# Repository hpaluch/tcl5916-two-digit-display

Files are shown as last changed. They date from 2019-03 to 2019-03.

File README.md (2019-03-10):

# Connecting 7-segment 2-digit display to TLC5916

Here is project how to use 2x TLC5916 with 7-segment 2-digit
LED display.

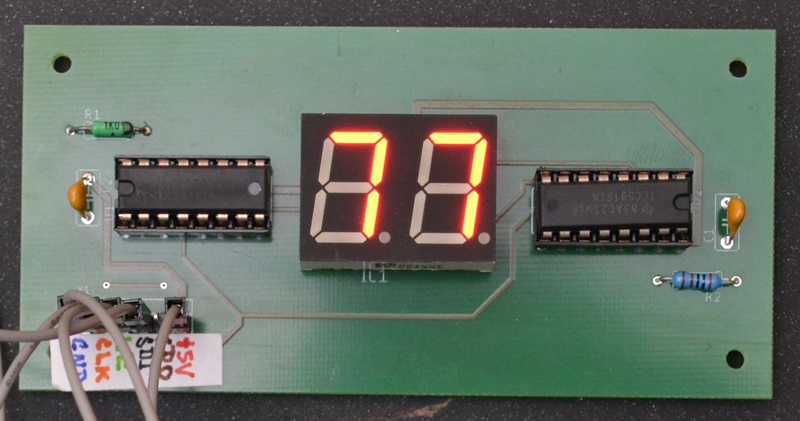
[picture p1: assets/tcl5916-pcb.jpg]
PCB with TLC5916 in action
 

Board revision 1.0 (initial) is shown on picture.

Project status:

Board was tested successfully. See 
subproject [Connecting TLC5916 to PC using LC 341A USB adapter][Connecting TLC5916 to PC using LC 341A USB adapter] for example.

# Design files

Design files are in revision 1.1, 2019-03-10. New values
of R1 and R2 were computed using this setup:

The relation between R<sub>ext</sub> and I<sub>led</sub> is following
(default configuration after power-up):

1. To get `I_led` in `[mA]` from `R_ext` in `[kOhm]` use:

   ```
   I_led = 1.25 * 15 / R_ext = 18.75 / R_ext
   ```
   
   For example (used in our circuit now): `R_ext = 1 [kOhm]` => `I_led = 18.75 [mA]` 
   
2. To get `R_ext` in `[kOhm]` from `I_led` in `[mA]` use:

   ```
   R_ext = 1.25 * 15 / I_led = 18.75 / I_led
   ```    

   For example: `I_led = 20 [mA]` => `R_ext = 0.937 [kOhm] = 937 [Ohm]`

Also see `Figure 4. Output Current vs Output Voltage` in data sheet
to verify that `VLED` (voltage connected to common LED anode) 
must be greater than `Voltage drop on LED` + `1V` (roughly).
In our case using `+5V` voltage is OK.

Design was done in [Eagle 9.3.0 Free][Eagle 9.3.0 Free]

Schematic is:

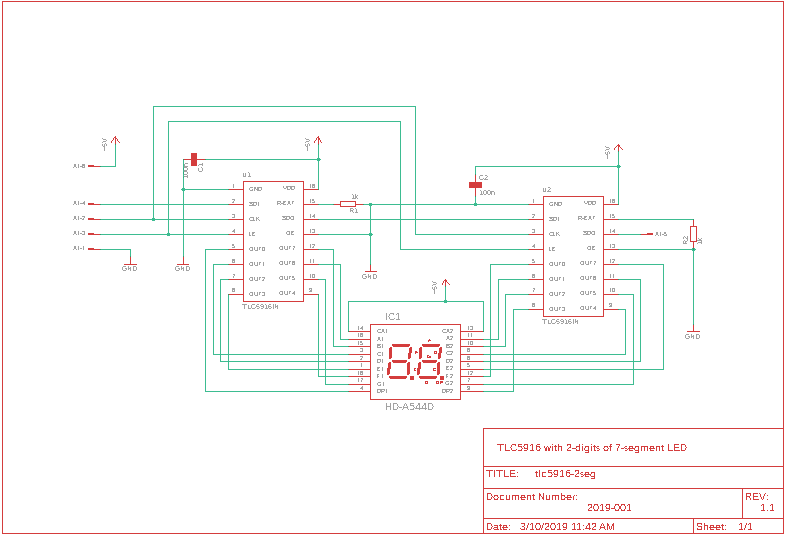
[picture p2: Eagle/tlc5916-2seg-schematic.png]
Schematic of TLC5916 with LED display
 

Also in:
* [PDF version][Schematic PDF]
* [Eagle 9.3.0 Free version][Schematic Eagle]

PCB design is:

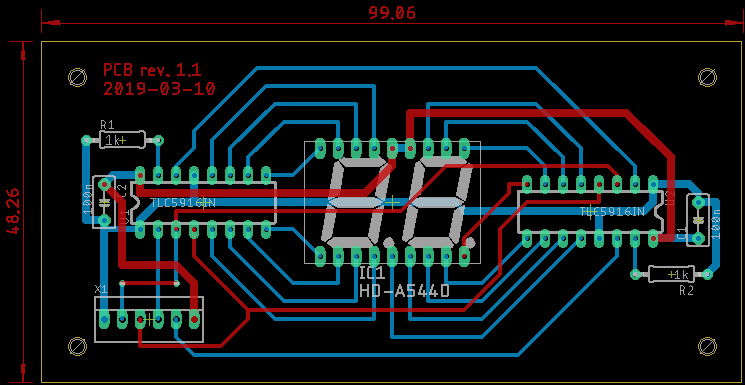
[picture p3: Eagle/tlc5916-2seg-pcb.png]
PCB of TLC5916 with LED display
 

Also in:
* [PDF version][PCB PDF]
* [Eagle 9.3.0 Free version][PCB Eagle]

Following Eagle libraries were used:

* [zlalanne/eagle-library][zlalanne/eagle-library] for
  definition of [TLC5916][TLC5916]
* [moje.lbr][moje.lbr] - my own part library (originally for Eagle 3/DOS)
  made in late 90's in college - 
  used definition of [2-digit HD-A544D LED display][HD-A544D]

Board was made by [gatema.cz][gatema.cz] for
around 700 CZK (roughly 32 USD) including:

* 2 layers
* plated holes
* solder mask
* top silk screen

NOTE: Remember to follow instructions in 
[eagle-dokumentace.pdf][eagle-dokumentace.pdf]
from [Technicke informace][Technicke informace]
(provided in Czech only)

# Bill of Material

* 2x [TLC5916][TLC5916 - tme.eu] - from tme.eu
* LED display [HD-A544D][HD-A544D] - from gme.cz
* 2x 1K resistor - from my inventory
* 2x 100nF capacitor - from my inventory
* pinhead connector 6 pins in 1 row - used
  20-pin [DS1021-1x20SF1-10][DS1021-1x20SF1-10] - from gme.cz

# Connecting TLC5916 to Interfaces

There are following subprojects:
* [Connecting TLC5916 to PC using LC 341A USB adapter][Connecting TLC5916 to PC using LC 341A USB adapter] - connecting
  this board to PC with USB adapter

# Known bugs/limitations

Design shortcomings:
* digital signals (`CLK`, `SDI`, `SDO`, `LE`) should be routed more
  carefully - not crossing `LED` lines (where are high current spikes).
* LED display power supply pins (`13` and `14`) should be
  wired  to `+5V` supply through jumper pins
  to allow custom power supply (for example `+12V`) different
  from main circuit `+5V` power supply.

[Technicke informace]: https://www.gatema.cz/plosne-spoje/technicke-informace/default/7?do=reloadInfo
[eagle-dokumentace.pdf]: http://www.gatema.cz/file-link/eagle-dokumentace.pdf
[gatema.cz]: https://extranet.gatema.cz/dps/konfiguratorpool.aspx
[DS1021-1x20SF1-10]: https://www.gme.cz/oboustranny-kolik-s1g20-2-54mm-v-13-80mm
[TLC5916 - tme.eu]: https://www.tme.eu/en/details/tlc5916in/led-drivers/texas-instruments/
[Connecting TLC5916 to PC using LC 341A USB adapter]: https://github.com/hpaluch/tlc5916-two-digit-display/tree/master/ch341-tlc5916
[HD-A544D]: https://www.gme.cz/led-display-14-2mm-red-hd-a544d
[moje.lbr]: https://github.com/hpaluch/tlc5916-two-digit-display/blob/master/Eagle/moje.lbr?raw=true
[TLC5916]: http://www.ti.com/lit/ds/slvs695d/slvs695d.pdf
[zlalanne/eagle-library]: https://github.com/zlalanne/eagle-library/blob/master/lbr/zlalanne.lbr
[PCB Eagle]: https://github.com/hpaluch/tlc5916-two-digit-display/blob/master/Eagle/tlc5916-2seg.brd?raw=true
[PCB PDF]: https://github.com/hpaluch/tlc5916-two-digit-display/blob/master/Eagle/tlc5916-2seg-pcb.pdf?raw=true
[Schematic Eagle]: https://github.com/hpaluch/tlc5916-two-digit-display/blob/master/Eagle/tlc5916-2seg.sch?raw=true
[Schematic PDF]: https://github.com/hpaluch/tlc5916-two-digit-display/blob/master/Eagle/tlc5916-2seg-sch.pdf?raw=true
[Eagle 9.3.0 Free]: https://www.autodesk.com/products/eagle/free-download

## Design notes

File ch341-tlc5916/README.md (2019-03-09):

# Connecting TLC5916 to PC using LC 341A USB adapter

> WARNING!
>
> Work in progress.

>  Currently sends `0` to `0xF` decoded to
>  to 1st and to 2nd digits (showing same value on both digits)

Please see [master project README][2-digit 7-segment LED with TLC5916]
for Schematic and/or PCB.

Here is VisualStudio 2010 project to control 
[2-digit 7-segment LED with TLC5916][2-digit 7-segment LED with TLC5916]
using 
[CH341A USB to UART/IIC/SPI/TTL/ISP adapter EPP/MEM Parallel converter][CH341A USB to UART/IIC/SPI/TTL/ISP adapter EPP/MEM Parallel converter]

Please see one of my CH341 projects, for example
[Accessing Microwire EEPROM 93LC86 from LC CH341A USB using SPI mode][Accessing Microwire EEPROM 93LC86 from LC CH341A USB using SPI mode]
for generic HW/SW setup instructions. Here is project specific info only.

# Wiring LC CH341A USB adapter with [TLC5916 LED board][2-digit 7-segment LED with TLC5916] and Logic Analyzer

Wire all 3 things together using table below:

|CH341A pin|Direction from CH341A|TLC5916 pin|Logic Analyzer pin|Description|
|---|---|---|---|---|
|GND|N/A|GND|GND|Common ground|
|CS0|Output|LE|CH1|Latch Enable - active in HIGH|
|CS1|Output|CLK|CH2|Clock - active in rising edge|
|CS2|Output|N/A|CH4|Fake /SS (slave select)<sup>1</sup>|
|MOSI|Output|SDI|CH3|serial data for TLC5916|

NOTE: The [TLC5916 LED board][2-digit 7-segment LED with TLC5916]
      uses its own `+5V` power supply,
      because the drawn current can be quite high - because
      of up to 16 LED lighting together...

<sup>1</sup>) trick so SPI decoder in Logic Analyzer will work with these data
  (that are not otherwise SPI compatible)

# Logic Analyzer output

Here is sample output sending 0xA5 data to TLC5916 (just for test):

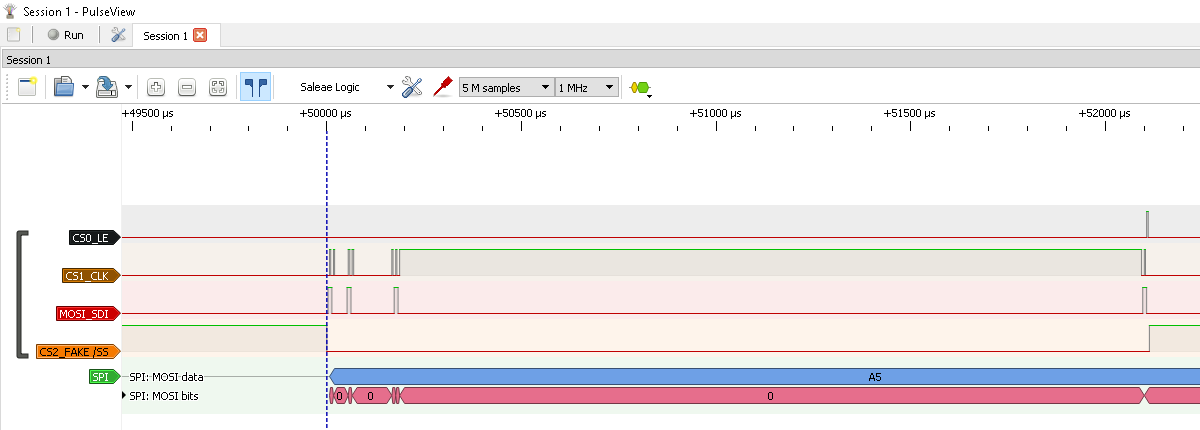
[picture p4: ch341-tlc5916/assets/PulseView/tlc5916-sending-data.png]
Sending data to TLC5916


[Accessing Microwire EEPROM 93LC86 from LC CH341A USB using SPI mode]: https://github.com/hpaluch/ch341-spi-93lc86 
[CH341A USB to UART/IIC/SPI/TTL/ISP adapter EPP/MEM Parallel converter]: http://www.chinalctech.com/cpzx/Programmer/Serial_Module/2019/0124/266.html 
[2-digit 7-segment LED with TLC5916]: https://github.com/hpaluch/tlc5916-two-digit-display

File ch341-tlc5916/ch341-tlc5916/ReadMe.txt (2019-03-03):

========================================================================
    CONSOLE APPLICATION : ch341-tlc5916 Project Overview
========================================================================

AppWizard has created this ch341-tlc5916 application for you.

This file contains a summary of what you will find in each of the files that
make up your ch341-tlc5916 application.

ch341-tlc5916.vcxproj
    This is the main project file for VC++ projects generated using an Application Wizard.
    It contains information about the version of Visual C++ that generated the file, and
    information about the platforms, configurations, and project features selected with the
    Application Wizard.

ch341-tlc5916.vcxproj.filters
    This is the filters file for VC++ projects generated using an Application Wizard. 
    It contains information about the association between the files in your project 
    and the filters. This association is used in the IDE to show grouping of files with
    similar extensions under a specific node (for e.g. ".cpp" files are associated with the
    "Source Files" filter).

ch341-tlc5916.cpp
    This is the main application source file.

/////////////////////////////////////////////////////////////////////////////
Other standard files:

StdAfx.h, StdAfx.cpp
    These files are used to build a precompiled header (PCH) file
    named ch341-tlc5916.pch and a precompiled types file named StdAfx.obj.

/////////////////////////////////////////////////////////////////////////////
Other notes:

AppWizard uses "TODO:" comments to indicate parts of the source code you
should add to or customize.

/////////////////////////////////////////////////////////////////////////////

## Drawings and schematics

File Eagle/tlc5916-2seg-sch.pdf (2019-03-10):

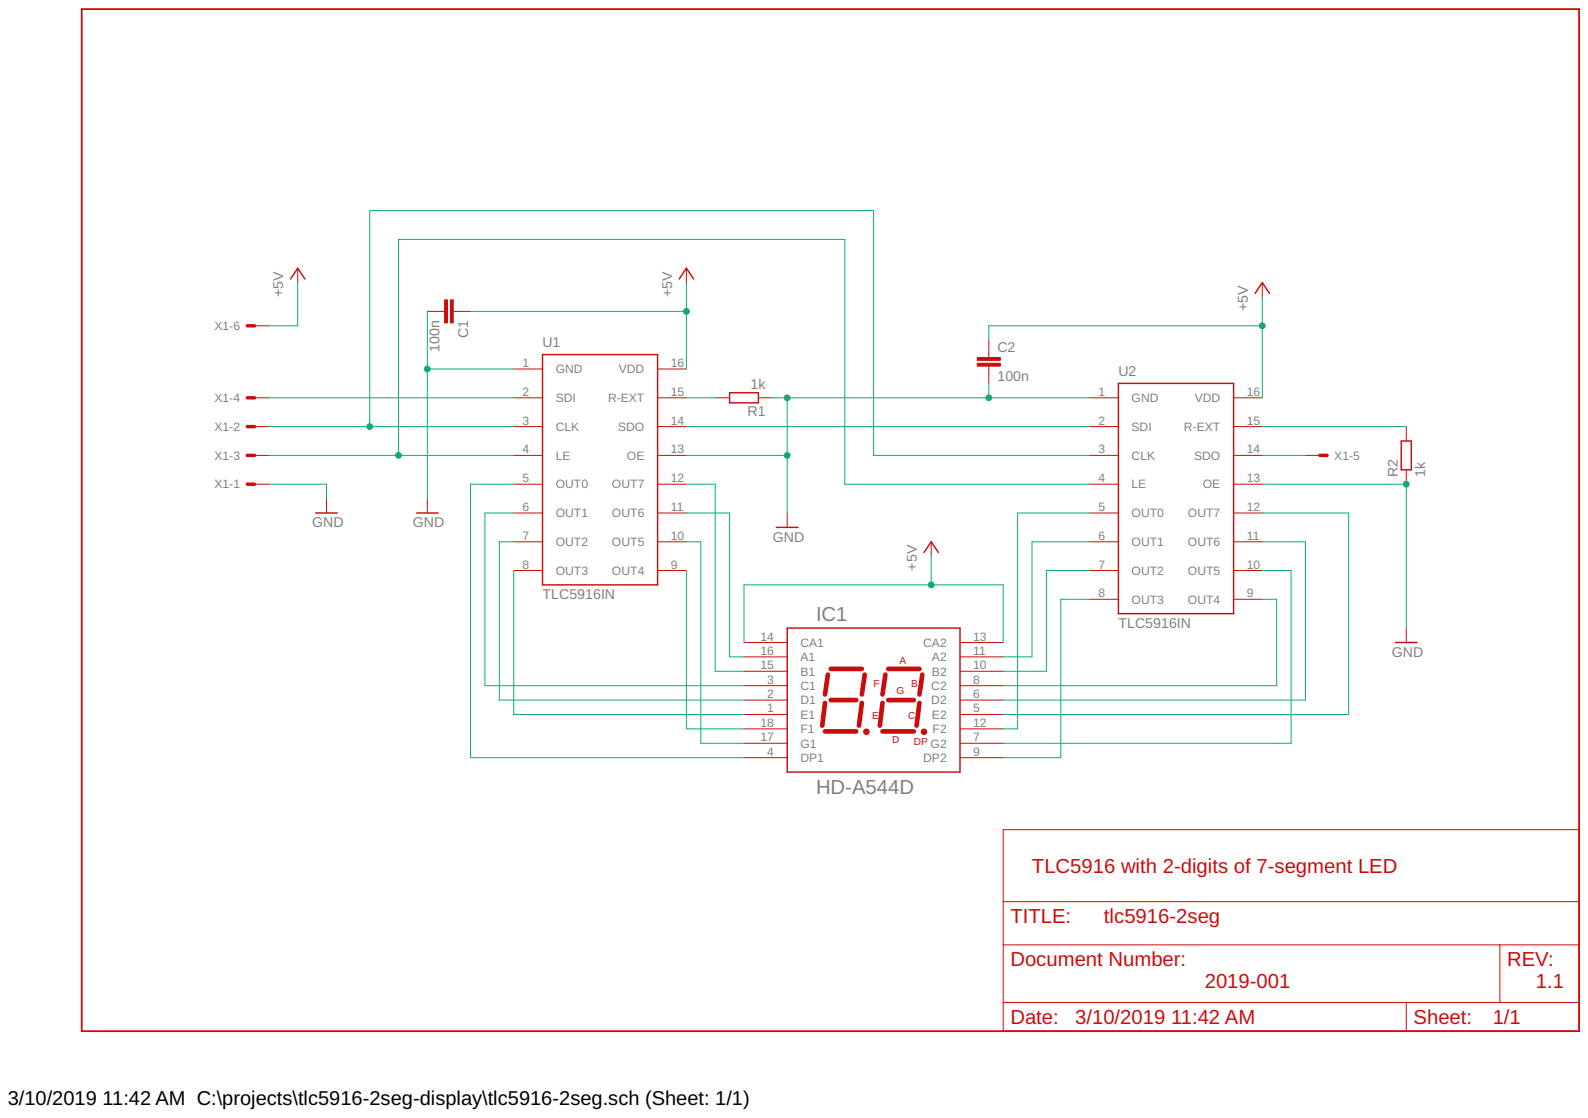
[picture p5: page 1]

TLC5916 with 2-digits of 7-segment LED

Document Number: 2019-001 | REV: 1.1

Date: 3/10/2019 11:42 AM | Sheet: 1/1

3/10/2019 11:42 AM C:\projects\tlc5916-2seg-display\tlc5916-2seg.sch (Sheet: 1/1)

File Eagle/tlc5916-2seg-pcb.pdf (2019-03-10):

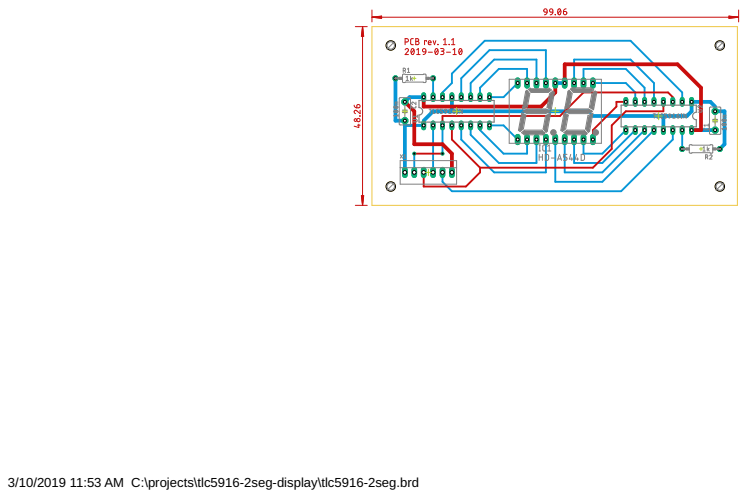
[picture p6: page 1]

3/10/2019 11:53 AM C:\projects\tlc5916-2seg-display\tlc5916-2seg.brd

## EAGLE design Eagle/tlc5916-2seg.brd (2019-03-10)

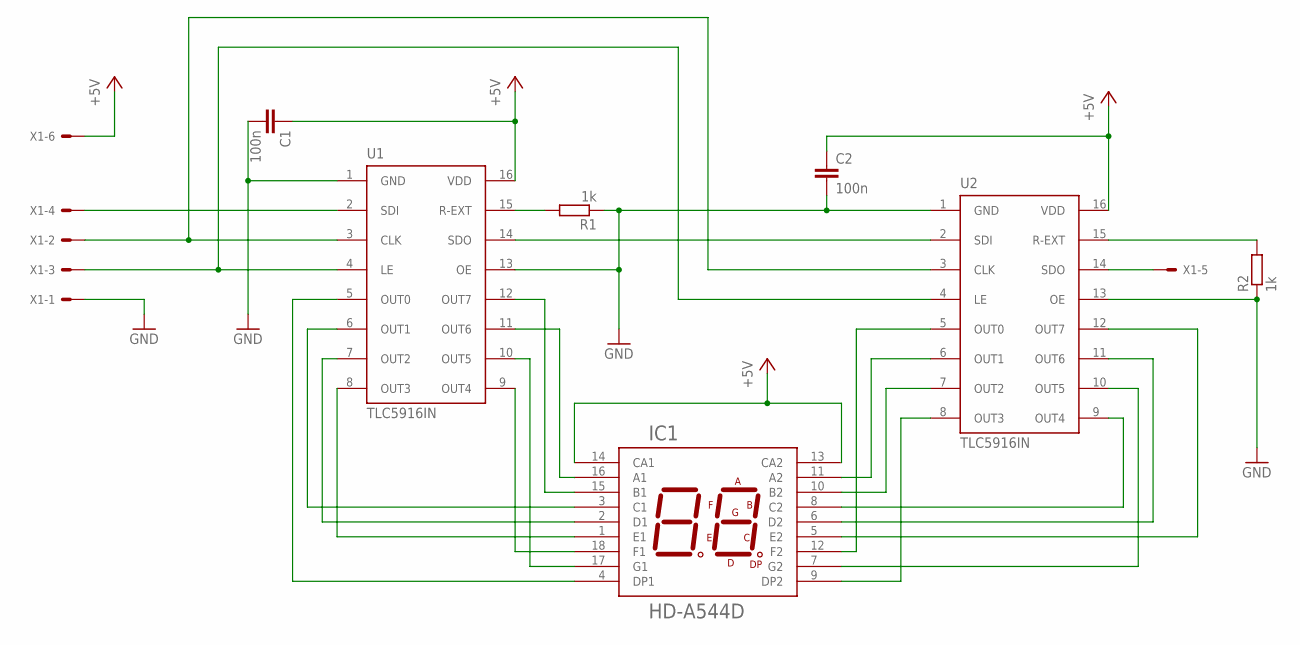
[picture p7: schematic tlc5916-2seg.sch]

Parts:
C1, C2: 100n; C5B3
IC1: HD-A544D; DIL18-SE
R1, R2: 1k; 0207/10
U1, U2: TLC5916IN; DIL16
X1: 22-23-2061

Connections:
+5V: C1.1, C2.1, IC1.13 (CA2), IC1.14 (CA1), U1.16 (VDD), U2.16 (VDD), X1.6
GND: C1.2, C2.2, R1.1, R2.1, U1.1 (GND), U1.13 (OE), U2.1 (GND), U2.13 (OE), X1.1
unnamed: R1.2, U1.15 (R-EXT)
unnamed: U1.3 (CLK), U2.3 (CLK), X1.2
unnamed: U1.4 (LE), U2.4 (LE), X1.3
unnamed: U1.2 (SDI), X1.4
unnamed: U1.14 (SDO), U2.2 (SDI)
unnamed: U2.14 (SDO), X1.5
unnamed: IC1.15 (B1), U1.12 (OUT7)
unnamed: R2.2, U2.15 (R-EXT)
unnamed: IC1.16 (A1), U1.11 (OUT6)
unnamed: IC1.17 (G1), U1.10 (OUT5)
unnamed: IC1.18 (F1), U1.9 (OUT4)
unnamed: IC1.1 (E1), U1.8 (OUT3)
unnamed: IC1.2 (D1), U1.7 (OUT2)
unnamed: IC1.3 (C1), U1.6 (OUT1)
unnamed: IC1.4 (DP1), U1.5 (OUT0)
unnamed: IC1.12 (F2), U2.5 (OUT0)
unnamed: IC1.11 (A2), U2.6 (OUT1)
unnamed: IC1.10 (B2), U2.7 (OUT2)
unnamed: IC1.9 (DP2), U2.8 (OUT3)
unnamed: IC1.8 (C2), U2.9 (OUT4)
unnamed: IC1.7 (G2), U2.10 (OUT5)
unnamed: IC1.6 (D2), U2.11 (OUT6)
unnamed: IC1.5 (E2), U2.12 (OUT7)

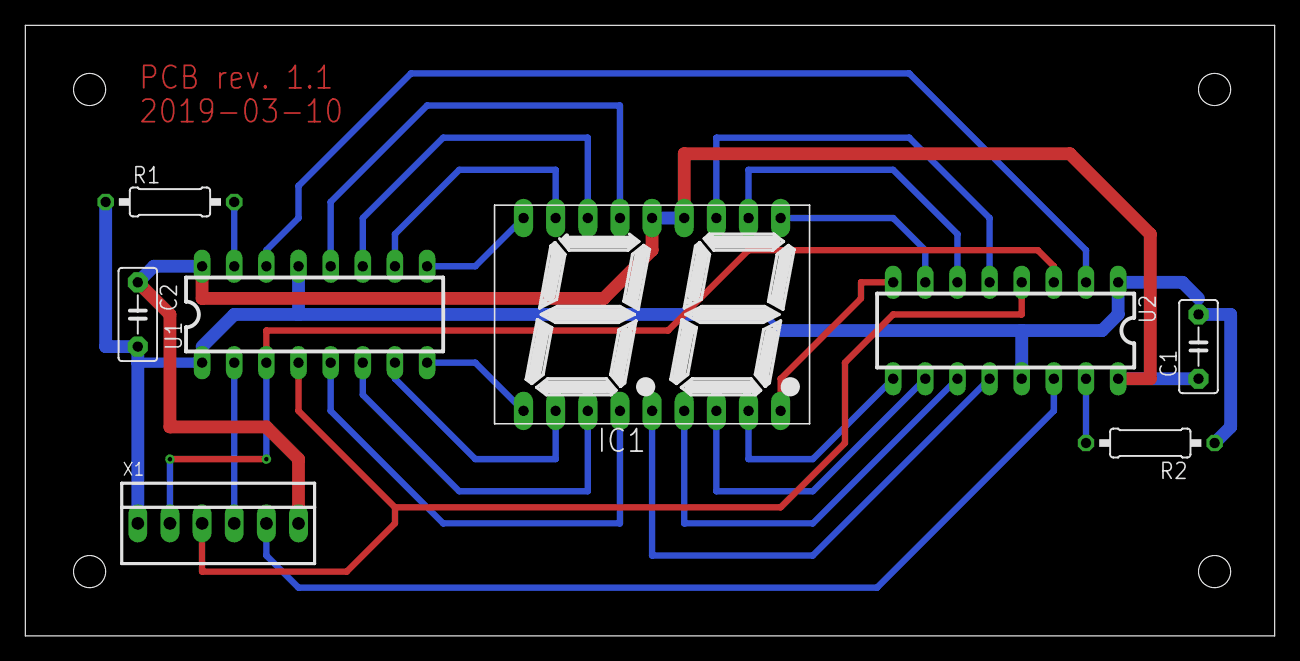
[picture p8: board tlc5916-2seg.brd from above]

Board: 2 copper layers, 98.7 x 48.2 mm, 8 parts (0 on the bottom side), 25 nets.

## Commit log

2019-03-03 Design files
    [tlc5916-2seg.brd, tlc5916-2seg.sch]
2019-03-03 Use 'Fake /SS' signal for SPI decoder in Logic Analyzer
2019-03-03 Added BOM
2019-03-09 Support for 2 digits - tested on PCB
2019-03-09 Added photo of finished PCB
2019-03-10 Updted R1, R2 to 1K (from 5K), added schematics Frame
    [tlc5916-2seg.sch]
2019-03-10 Fixed R1, R2 values, added revision number to PCB
    [tlc5916-2seg.brd]
